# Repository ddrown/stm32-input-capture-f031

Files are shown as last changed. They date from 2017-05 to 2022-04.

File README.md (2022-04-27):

This was originally designed to accept a very low frequency pwm output (1-50Hz) and measure the SBC's frequency vs the TCXO's. That frequency data can then be fed into chrony's temperature compensation system to result in more stable time for NTP service.

Hardware is a custom designed SBC hat with microcontroller and TCXO

The TCXO's frequency vs temperature curve is measured and stored in flash in order to increase long term frequency accuracy.

The hat also contains an RTC with sub-second precision. Usually i2c RTCs will only tell you time to the nearest second, so you have to poll them to find out when the second changes. The RTC runs off the 32khz crystal, but can be measured in hardware against the TCXO with `clients/rtc compare`

Timers used
* TIM2 - main 32 bit timer, all 4 channels are setup as input capture
* TIM14 - 16 bit timer, measures RTC vs TCXO on channel 1

settings in raspi-config:

i2c enabled
(optional for gps) serial login shell disabled, serial interface enabled

/boot/config.txt:
dtparam=i2c\_arm=on
dtparam=i2c\_arm\_baudrate=400000
\# optional for gps
dtoverlay=pps-gpio,gpiopin=13

stm32 source code:

* Src/system_stm32f0xx.c - bootup, start clocks
* Src/main.c - init peripherals, main loop
* Src/stm32f0xx_hal_msp.c - init irq, init gpio routing, init clocks, etc
* Src/stm32f0xx_it.c - irq handlers (mostly call into HAL)
* Src/adc.c - measure temperature, vcc, and rtc battery
* Src/flash.c - store TCXO parameters in flash
* Src/i2c_slave.c - i2c interface to talk to SBC
* Src/timer.c - manages TIM2, TIM14, and RTC
* Src/uart.c - debug uart interface
* Drivers/STM32F0xx_HAL_Driver - stm32 Hardware Abstraction Layer (HAL)

SBC tool code:

* clients/timestamps-i2c.c - compare SBC system time vs TCXO, request via i2c
* clients/input-capture-i2c.c - compare SBC system frequency vs TCXO, via SBC output pwm
* clients/pi-pwm-setup.c - wiringPi setup SBC output pwm
* clients/pi-pwm-disable.c - wiringPi disable SBC output pwm
* clients/odroid-c2-setup - sysfs setup SBC output pwm
* clients/rtc.c - read/set/sync/manage rtc
* clients/set-calibration-data.c - get/set TCXO calibration data in flash
* clients/ds3231.c - DS3231 RTC i2c client
* clients/pcf2129.c - PCF2129 RTC i2c client
* clients/calibration.c - measure RTC vs TCXO
* clients/dump-adc.c - test comparing floating vs fixed point math

SBC library code:

* clients/adc_calc.c - read ADC data over i2c
* clients/aging.c - estimate TCXO frequency from aging effects
* clients/avg.c - calculate averages
* clients/float.c - convert between native float and i2c compatible
* clients/i2c.c - i2c interface functions
* clients/i2c_registers.c - read stm32's exported data via i2c
* clients/rtc_data.c - convert between RTC data and system time
* clients/tempcomp.c - calculate TCXO's temperature compensation
* clients/timespec.c - struct timespec utilities
* clients/vref_calc.c - adc voltage calculations

Programming the stm32 can be done via openocd on the connected SBC.

SWD programming interface is connected to SBC pins:
* 18 - dio
* 22 - clk
* 11 - rst

Example openocd configuration:
* openocd.cfg - raspberry pi & stlink example
* openocd-odroid.cfg - gpio sysfs on odroid-c2 SBC

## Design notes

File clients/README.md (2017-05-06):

# Clients to talk to the stm32 hardware

Tested clients: Raspberry Pi, Odroid C2

 * pi-pwm-setup.c - setup PWM output for the Raspberry Pi (50Hz on GPIO18 / Pin #12)
 * odroid-c2-setup - setup PWM output for the Odroid C2 (50Hz on GPIOX\_6 / Pin #33)
 * input-capture-i2c.c - poll the stm32 every second and write the average frequency over the past 128s to /run/tcxo
 * timespec.c - nanosecond timestamps handling
 * i2c.c - i2c bus code
 * ds3231.c - setup RTC DS3231 (optional)
 * rtc.c - manage rtc
 * calibration.c - dump i2c registers 1/s
 * set-calibration-data.c - set/get i2c registers
 * pihatrtc.service - put this in /etc/systemd/system/ and enable it with "systemctl enable pihatrtc"

Example chrony.conf line: `tempcomp /run/tcxo 1 0 0 1 0`

Currently setup to expect 50Hz on channel 1, 1Hz on channels 2-4.  set-calibration-data can change this

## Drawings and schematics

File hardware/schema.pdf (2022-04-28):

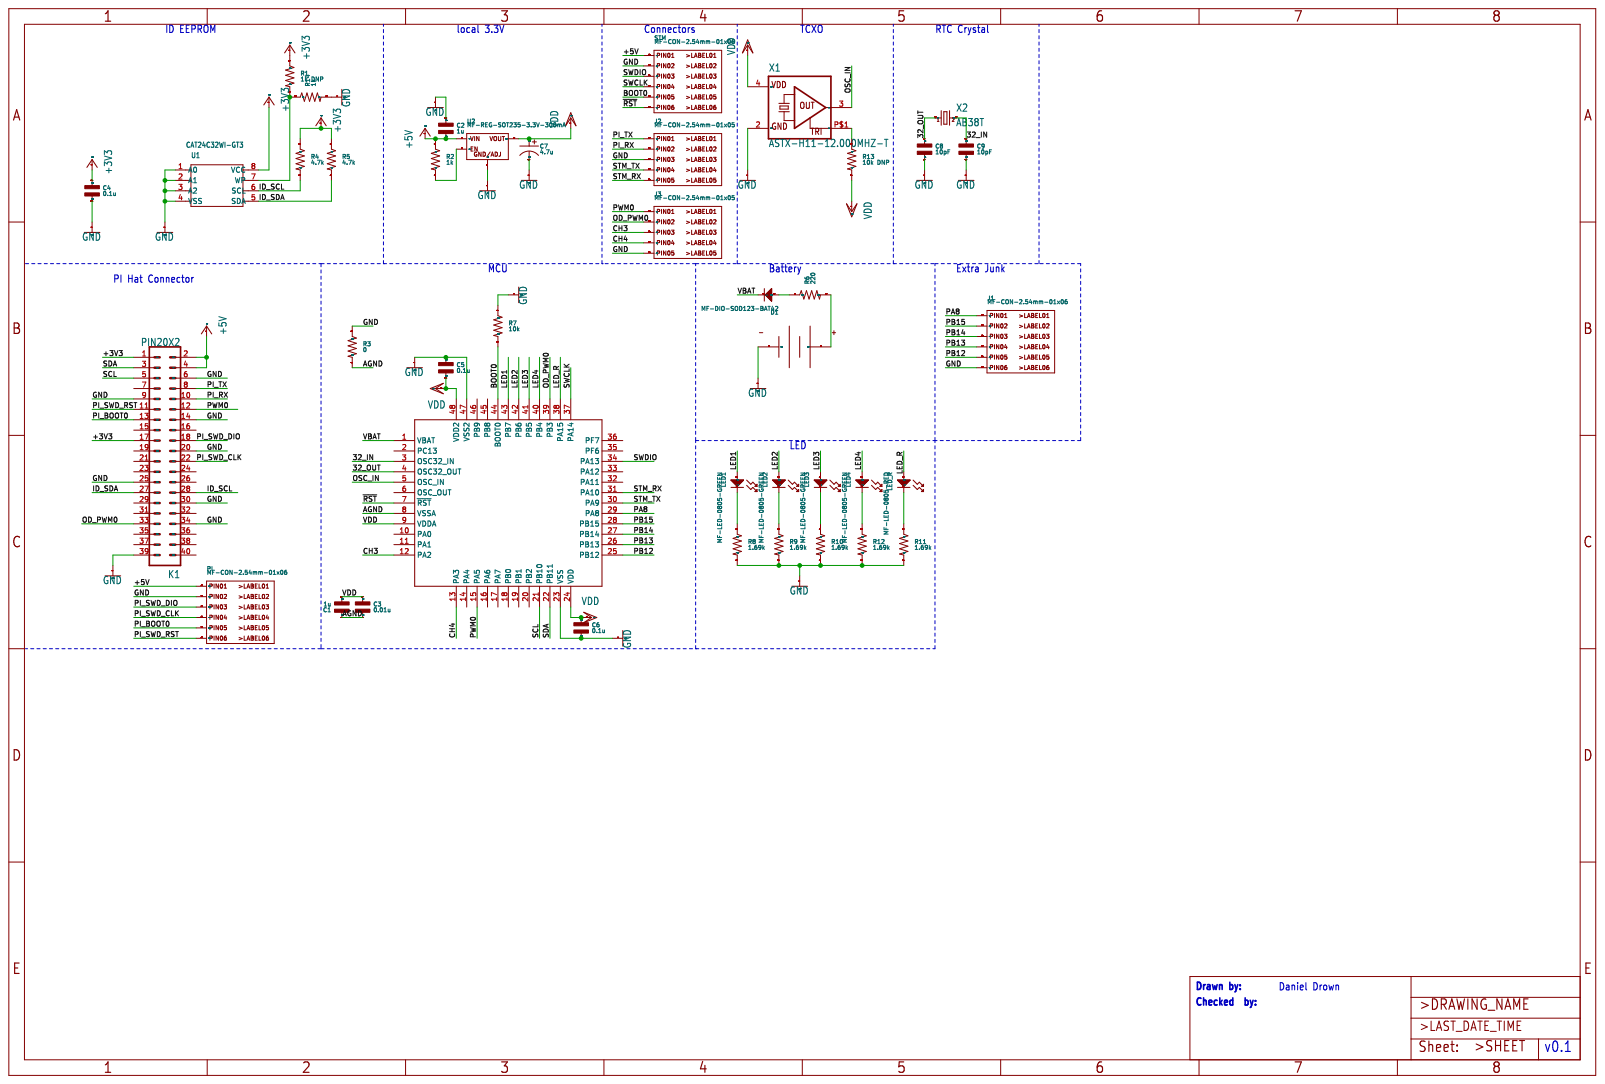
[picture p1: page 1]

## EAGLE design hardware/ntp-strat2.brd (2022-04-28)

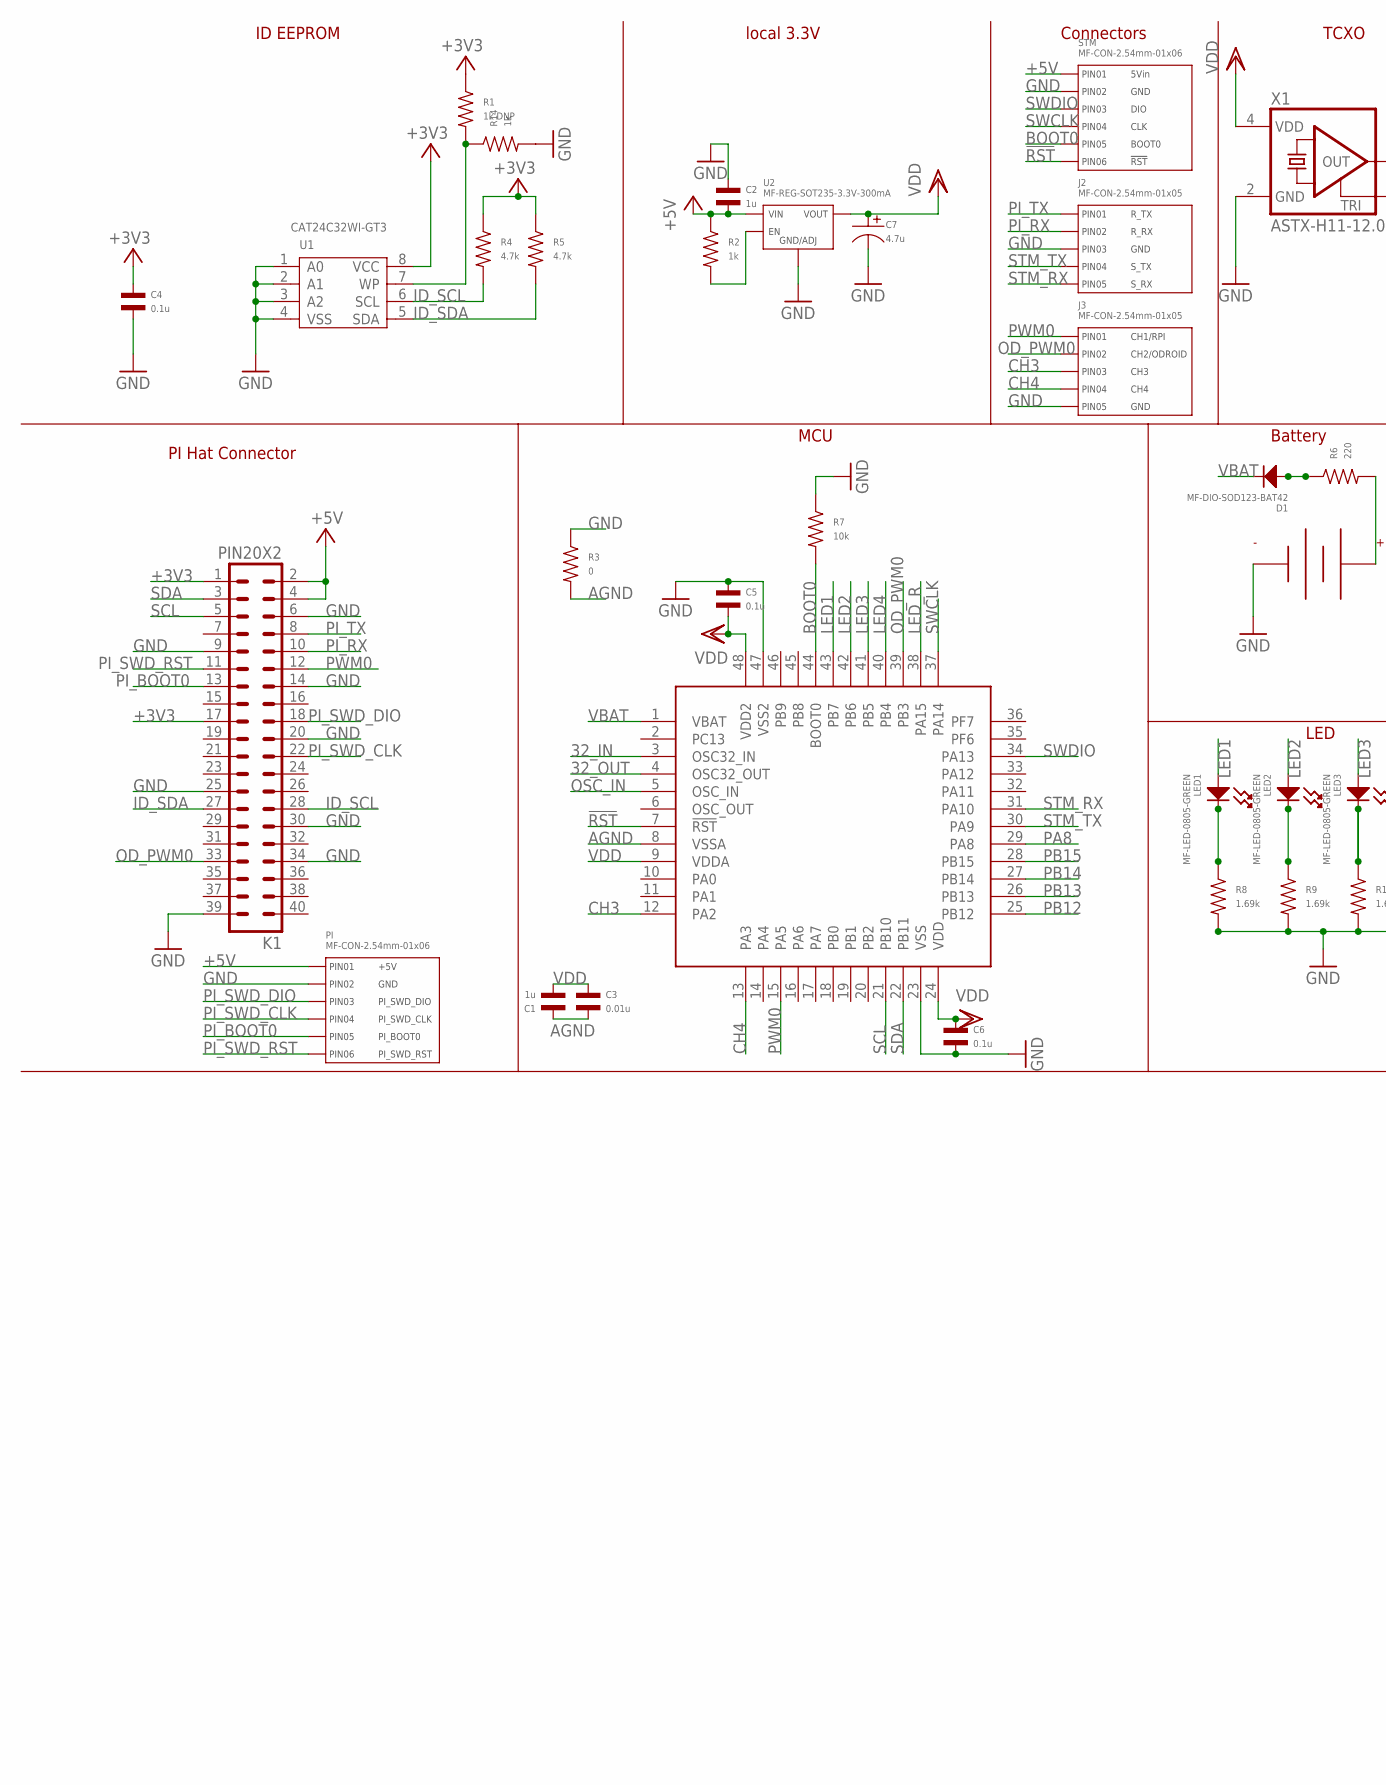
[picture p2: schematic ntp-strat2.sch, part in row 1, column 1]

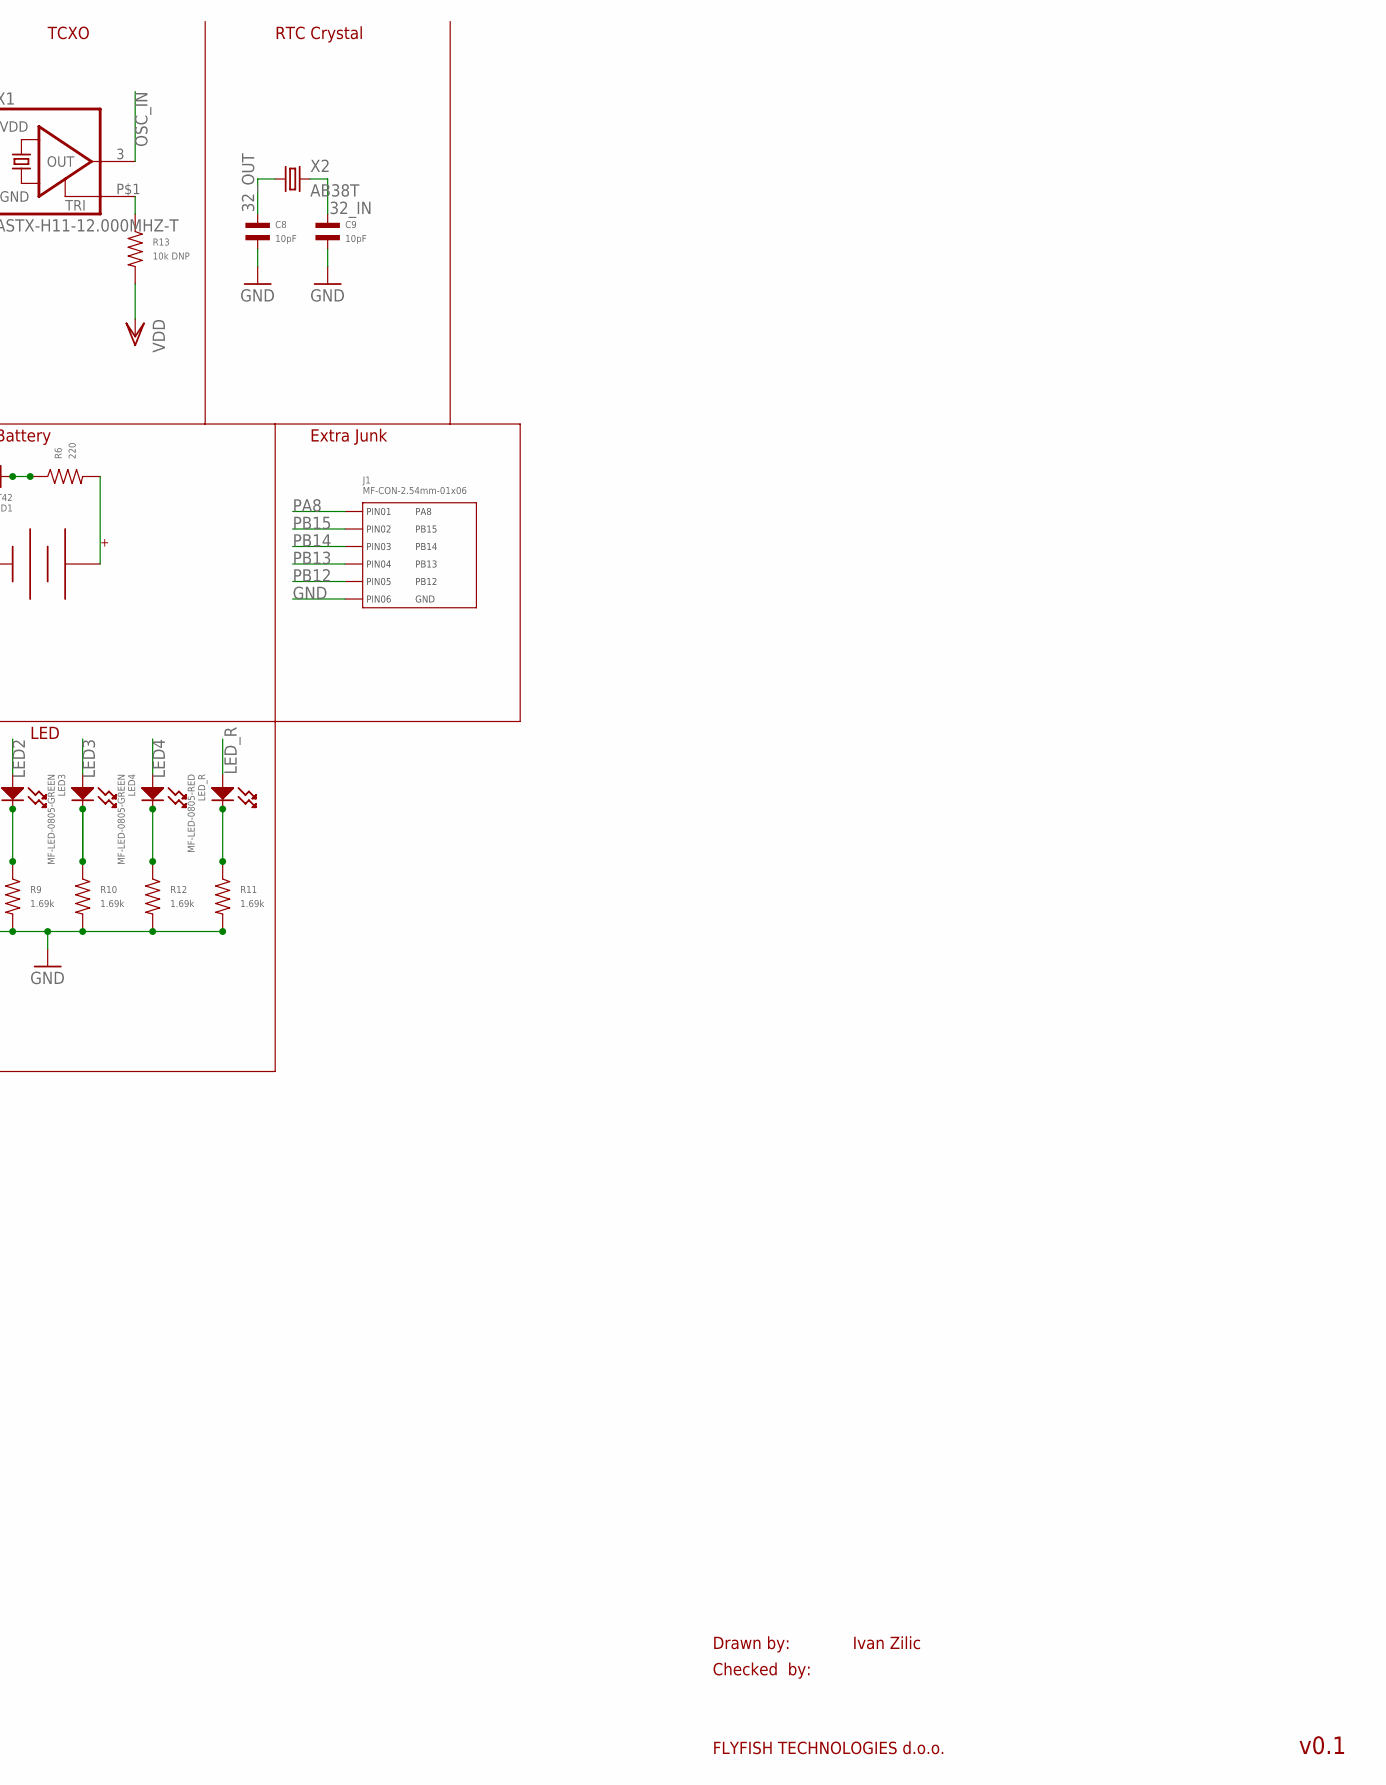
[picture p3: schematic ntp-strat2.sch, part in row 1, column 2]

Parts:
C1, C2: 1u; C0603
C3: 0.01u; C0603
C4, C5, C6: 0.1u; C0603
C7: 4.7u; CP4MM
C8, C9: 10pF; C0603
D1: MF-DIO-SOD123-BAT42; SOD-123
J1: MF-CON-2.54mm-01x06; PTH_2.54MM_01X06
J2, J3: MF-CON-2.54mm-01x05; PTH_2.54MM_01X05
K1: PIN20X2; PIN_20X2
LED1, LED2, LED3, LED4: MF-LED-0805-GREEN; LED0805
LED_R: MF-LED-0805-RED; LED0805
PI: MF-CON-2.54mm-01x06; PTH_2.54MM_01X06
R1: 1k DNP; R0603
R2, R14: 1k; R0603
R3: 0; R0603
R4, R5: 4.7k; R0603
R6: 220; R0603
R7: 10k; R0603
R8, R9, R10, R11, R12: 1.69k; R0603
R13: 10k DNP; R0603
STM: MF-CON-2.54mm-01x06; PTH_2.54MM_01X06
U1: CAT24C32WI-GT3; SOIC8-1.27-5X4MM
U2: MF-REG-SOT235-3.3V-300mA; SOT-23-5
U3: STM32F031C6T6; LQFP48-7X7
U4: BU2032SM-BT-GTR; BU2032SM
X1: ASTX-H11-12.000MHZ-T; ASVTX
X2: AB38T

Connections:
32_IN: C9.P$1, U3.3 (OSC32_IN), X2.P2 (2)
32_OUT: C8.P$1, U3.4 (OSC32_OUT), X2.P1 (1)
!RST: STM.P$6 (PIN6), U3.7 (!RST)
+3V3: C4.P$1, K1.1, K1.17, R1.P$1, R4.P$1, R5.P$1, U1.8 (VCC)
+5V: C2.P$2, K1.2, K1.4, PI.P$1 (PIN1), R2.P$1, STM.P$1 (PIN1), U2.P$1 (VIN)
AGND: C1.P$1, C3.P$2, R3.P$2, U3.8 (VSSA)
BOOT0: R7.P$2, STM.P$5 (PIN5), U3.44 (BOOT0)
CH3: J3.P$3 (PIN3), U3.12 (PA2)
CH4: J3.P$4 (PIN4), U3.13 (PA3)
GND: C2.P$1, C4.P$2, C5.P$1, C6.P$2, C7.P$2, C8.P$2, C9.P$2, J1.P$6 (PIN6), J2.P$3 (PIN3), J3.P$5 (PIN5), K1.6, K1.9, K1.14, K1.20, K1.25, K1.30, K1.34, K1.39, PI.P$2 (PIN2), R3.P$1, R7.P$1, R8.P$2, R9.P$2, R10.P$2, R11.P$2, R12.P$2, R14.P$2, STM.P$2 (PIN2), U1.1 (A0), U1.2 (A1), U1.3 (A2), U1.4 (VSS), U2.P$2 (GND/ADJ), U3.23 (VSS), U3.47 (VSS2), U4.MINUS, X1.2 (GND)
ID_SCL: K1.28, R4.P$2, U1.6 (SCL)
ID_SDA: K1.27, R5.P$2, U1.5 (SDA)
LED1: LED1.ANODE, U3.43 (PB7)
LED2: LED2.ANODE, U3.42 (PB6)
LED3: LED3.ANODE, U3.41 (PB5)
LED4: LED4.ANODE, U3.40 (PB4)
LED_R: LED_R.ANODE, U3.38 (PA15)
unnamed: R2.P$2, U2.P$3 (EN)
unnamed: LED1.CATHODE, R8.P$1
unnamed: R1.P$2, R14.P$1, U1.7 (WP)
unnamed: D1.ANODE, R6.P$1
unnamed: LED2.CATHODE, R9.P$1
unnamed: LED3.CATHODE, R10.P$1
unnamed: LED_R.CATHODE, R11.P$1
unnamed: LED4.CATHODE, R12.P$1
unnamed: R6.P$2, U4.PLUS
unnamed: R13.P$1, X1.P$1 (TRI)
OD_PWM0: J3.P$2 (PIN2), K1.33, U3.39 (PB3)
OSC_IN: U3.5 (OSC_IN), X1.3 (OUT)
PA8: J1.P$1 (PIN1), U3.29 (PA8)
PB12: J1.P$5 (PIN5), U3.25 (PB12)
PB13: J1.P$4 (PIN4), U3.26 (PB13)
PB14: J1.P$3 (PIN3), U3.27 (PB14)
PB15: J1.P$2 (PIN2), U3.28 (PB15)
PI_BOOT0: K1.13, PI.P$5 (PIN5)
PI_RX: J2.P$2 (PIN2), K1.10
PI_SWD_CLK: K1.22, PI.P$4 (PIN4)
PI_SWD_DIO: K1.18, PI.P$3 (PIN3)
PI_SWD_RST: K1.11, PI.P$6 (PIN6)
PI_TX: J2.P$1 (PIN1), K1.8
PWM0: J3.P$1 (PIN1), K1.12, U3.15 (PA5)
SCL: K1.5, U3.21 (PB10)
SDA: K1.3, U3.22 (PB11)
STM_RX: J2.P$5 (PIN5), U3.31 (PA10)
STM_TX: J2.P$4 (PIN4), U3.30 (PA9)
SWCLK: STM.P$4 (PIN4), U3.37 (PA14)
SWDIO: STM.P$3 (PIN3), U3.34 (PA13)
VBAT: D1.CATHODE, U3.1 (VBAT)
VDD: C1.P$2, C3.P$1, C5.P$2, C6.P$1, C7.P$1, R13.P$2, U2.P$5 (VOUT), U3.9 (VDDA), U3.24 (VDD), U3.48 (VDD2), X1.4 (VDD)

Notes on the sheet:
Drawn by:
Checked by:
FLYFISH TECHNOLOGIES d.o.o.
Ivan Zilic
v0.1
ID EEPROM
PI Hat Connector
local 3.3V
Connectors
TCXO
RTC Crystal
Battery
MCU
LED
Extra Junk

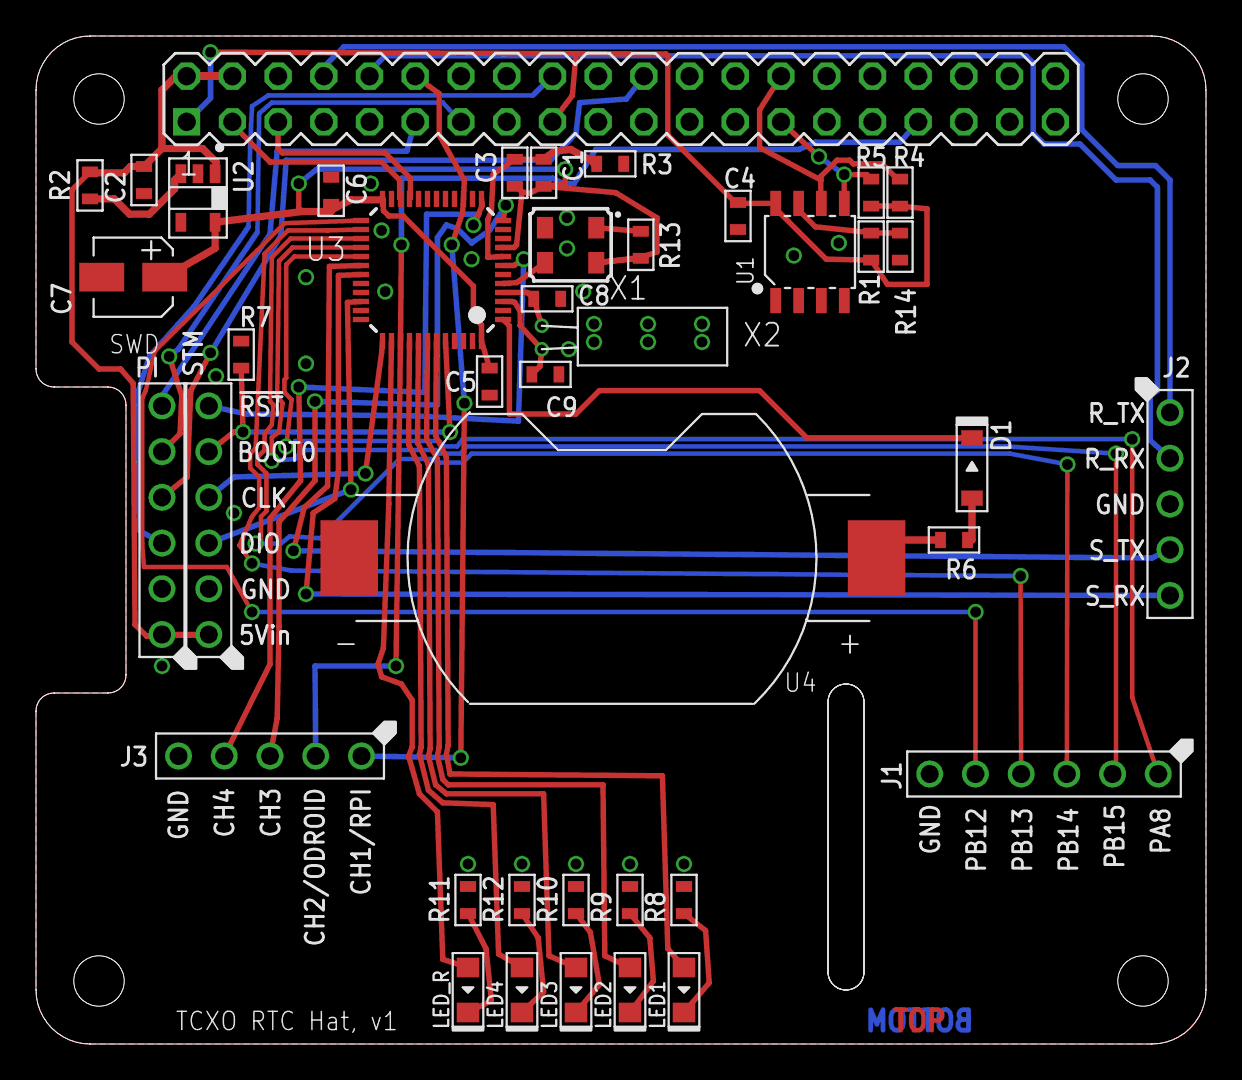
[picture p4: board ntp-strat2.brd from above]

Board: 2 copper layers, 65.0 x 56.0 mm, 41 parts (0 on the bottom side), 49 nets.

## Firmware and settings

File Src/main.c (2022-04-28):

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
/* Includes ------------------------------------------------------------------*/
#include "main.h"

/* USER CODE BEGIN Includes */
#include "uart.h"
#include "timer.h"
#include "i2c_slave.h"
#include "adc.h"
/* USER CODE END Includes */

 ADC_HandleTypeDef hadc;

I2C_HandleTypeDef hi2c1;

RTC_HandleTypeDef hrtc;

TIM_HandleTypeDef htim2;
TIM_HandleTypeDef htim14;

UART_HandleTypeDef huart1;

/* USER CODE BEGIN PV */

/* USER CODE END PV */

void SystemClock_Config(void);
static void MX_GPIO_Init(void);
static void MX_ADC_Init(void);
static void MX_I2C1_Init(void);
static void MX_RTC_Init(void);
static void MX_TIM2_Init(void);
static void MX_TIM14_Init(void);
static void MX_USART1_UART_Init(void);
/* USER CODE BEGIN PFP */

/* USER CODE END PFP */

/**
  * @brief  The application entry point.
  * @retval int
  */
int main(void)
{
  /* MCU Configuration--------------------------------------------------------*/

  /* Reset of all peripherals, Initializes the Flash interface and the Systick. */
  HAL_Init();

  /* Configure the system clock */
  SystemClock_Config();

  /* Initialize all configured peripherals */
  MX_GPIO_Init();
  MX_ADC_Init();
  MX_I2C1_Init();
  MX_RTC_Init();
  MX_TIM2_Init();
  MX_TIM14_Init();
  MX_USART1_UART_Init();
  /* USER CODE BEGIN 2 */
  HAL_ADCEx_Calibration_Start(&hadc);
  i2c_slave_start();
  timer_start();
  rtc_start();
  /* USER CODE END 2 */

  /* Infinite loop */
  /* USER CODE BEGIN WHILE */
  while (1)
  {
    /* USER CODE END WHILE */

    /* USER CODE BEGIN 3 */

    /* debugging code
    print_timer_status();
    i2c_show_data();
     */
    adc_poll();
    HAL_Delay(100);
  }
  /* USER CODE END 3 */
}

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


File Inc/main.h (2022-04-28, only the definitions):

#define LED_R_Pin GPIO_PIN_15
#define LED_R_GPIO_Port GPIOA
#define LED4_Pin GPIO_PIN_4
#define LED4_GPIO_Port GPIOB
#define LED3_Pin GPIO_PIN_5
#define LED3_GPIO_Port GPIOB
#define LED2_Pin GPIO_PIN_6
#define LED2_GPIO_Port GPIOB
#define LED1_Pin GPIO_PIN_7
#define LED1_GPIO_Port GPIOB

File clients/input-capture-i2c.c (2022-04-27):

#include <errno.h>
#include <stdlib.h>
#include <unistd.h>
#include <stdint.h>
#include <stdio.h>
#include <string.h>
#include <time.h>
#include <math.h>
#include <ctype.h>

#include "i2c.h"
#include "timespec.h"
#include "i2c_registers.h"
#include "adc_calc.h"
#include "vref_calc.h"
#include "aging.h"
#include "tempcomp.h"

#define SUMMARIZE_INTERVAL 64
struct per_second_stats {
  time_t when;
  uint32_t irq_to_i2c_ms;
  uint32_t status;
  uint32_t sleep_ms;
  double added_offset_ns[INPUT_CHANNELS];
  double tempcomp;
  float aging;
  double main_freq_32s;
  double main_freq_64s;
  float temp_f;
  float vref;
  float vbat;
} stats[SUMMARIZE_INTERVAL];
uint8_t stats_i = 0;

// current code assumptions: main channel never stops
struct icap_config {
  uint8_t verbose;
  uint8_t main_channel;
  uint8_t main_channel_hz;
} config;

#define AVERAGING_CYCLES 65
#define PPM_INVALID -1000000.0
#define AIM_AFTER_MS 5
#define TCXO_TEMPCOMP_TEMPFILE "/run/.tcxo"
#define TCXO_TEMPCOMP_FILE "/run/tcxo"
#define TCXO_FREQ_TEMPFILE "/run/.tcxo-freq"
#define TCXO_FREQ_FILE "/run/tcxo-freq"

// status_flags bitfields
#define STATUS_BAD_CH1        0b1
#define STATUS_BAD_CH2       0b10
#define STATUS_BAD_CH3      0b100
#define STATUS_BAD_CH4     0b1000
// BAD_CHANNEL_STATUS takes 0-indexed channels
#define BAD_CHANNEL_STATUS(x) (1 << (x))

static uint16_t wrap_add(int16_t a, int16_t b, uint16_t modulus) {
  a = a + b;
  if(a < 0) {
    a += modulus;
  }
  return a;
}

static uint16_t wrap_sub(int16_t a, int16_t b, uint16_t modulus) {
  return wrap_add(a, -1 * b, modulus);
}

static void print_ppm(float ppm) {
  if(ppm < 500 && ppm > -500) {
    printf("%1.3f ", ppm);
  } else {
    printf("- ");
  }
}

static void write_freqfile(float ppm, const char *tempfile, const char *finalfile) {
  FILE *tcxo;

  if(ppm > 500 || ppm < -500) {
    return;
  }

  tcxo = fopen(tempfile,"w");
  if(tcxo == NULL) {
    perror("fopen");
    printf("was trying to open file %s\n", tempfile);
    exit(1);
  }
  fprintf(tcxo, "%1.3f\n", ppm);
  fclose(tcxo);
  rename(tempfile, finalfile);
}

static void write_tcxo_ppm(float ppm) {
  write_freqfile(ppm, TCXO_FREQ_TEMPFILE, TCXO_FREQ_FILE);
}

static void write_tempcomp_ppm(float ppm) {
  write_freqfile(ppm, TCXO_TEMPCOMP_TEMPFILE, TCXO_TEMPCOMP_FILE);
}

// modifies cycles, first_cycle, last_cycle
static void store_added_offset(double added_offset_ns, struct timespec *cycles, uint16_t *first_cycle, uint16_t *last_cycle) {
  struct timespec *previous_cycle = NULL;
  uint16_t this_cycle_i;

  this_cycle_i = (*last_cycle + 1) % AVERAGING_CYCLES;
  if(*first_cycle != *last_cycle) {
    previous_cycle = &cycles[*last_cycle];
    if(*first_cycle == this_cycle_i) { // we've wrapped around, move the first pointer forward
      *first_cycle = (*first_cycle + 1) % AVERAGING_CYCLES;
    }
  }

  cycles[this_cycle_i].tv_sec = 0;
  cycles[this_cycle_i].tv_nsec = added_offset_ns;
  if(previous_cycle != NULL) {
    add_timespecs(&cycles[this_cycle_i], previous_cycle);
  }

  *last_cycle = this_cycle_i;
}

static float calc_ppm_2(struct timespec *end, struct timespec *start, uint16_t seconds) {
  double diff_s;
  struct timespec diff;
  diff.tv_sec = end->tv_sec;
  diff.tv_nsec = end->tv_nsec;

  sub_timespecs(&diff, start);
  diff_s = diff.tv_sec + diff.tv_nsec / 1000000000.0;

  float ppm = diff_s * 1000000.0 / seconds;
  return ppm;
}

static float calc_ppm(int16_t number_points, uint16_t last_cycle_index, uint16_t seconds, struct timespec *cycles) {
  float ppm = PPM_INVALID; // default: invalid PPM

  if(number_points >= seconds) {
    uint16_t start_index = wrap_sub(last_cycle_index, seconds, AVERAGING_CYCLES);
    ppm = calc_ppm_2(&cycles[last_cycle_index], &cycles[start_index], seconds);
  }

  return ppm;
}

static uint32_t calculate_sleep_ms(uint32_t milliseconds_now, uint32_t milliseconds_irq) {
  uint32_t sleep_ms = 1000 + AIM_AFTER_MS - (milliseconds_now - milliseconds_irq);
  if(sleep_ms > 1000+AIM_AFTER_MS) {
    sleep_ms = 1000+AIM_AFTER_MS;
  } else if(sleep_ms < 1) {
    sleep_ms = 1;
  }
  return sleep_ms;
}

// modifies added_offset_ns, status_flags
static int add_cycles(uint32_t *status_flags, double *added_offset_ns, const struct i2c_registers_type *i2c_registers) {
  static uint32_t previous_cycles[INPUT_CHANNELS] = {0,0,0,0};
  static uint8_t previous_count[INPUT_CHANNELS] = {0,0,0,0};
  static uint32_t primary_ms_last = 0;
  int retval = 1;

  for(uint8_t i = 0; i < INPUT_CHANNELS; i++) {
    int32_t diff;
    
    if(i == config.main_channel-1) {
      uint32_t milliseconds = i2c_registers->milliseconds_irq_primary - primary_ms_last;
      if(milliseconds < 2000 && milliseconds > 900) {
        diff = i2c_registers->tim2_at_cap[i] - previous_cycles[i] - EXPECTED_FREQ;
        added_offset_ns[i] = diff * 1000000000.0 / EXPECTED_FREQ;
      } else {
        added_offset_ns[i] = 0;
        retval = 0;
	*status_flags |= BAD_CHANNEL_STATUS(i);
      }
      primary_ms_last = i2c_registers->milliseconds_irq_primary;
    } else {
      uint8_t diff_count = i2c_registers->ch_count[i] - previous_count[i];

      if(diff_count == 1 || diff_count == 2) { // treating count as # of seconds, assume 1s/2s=ok, other values=invalid
	diff = i2c_registers->tim2_at_cap[i] - previous_cycles[i] - (EXPECTED_FREQ * diff_count);
	added_offset_ns[i] = diff * 1000000000.0 / (EXPECTED_FREQ * diff_count);
      } else {
	added_offset_ns[i] = 0;
	*status_flags |= BAD_CHANNEL_STATUS(i);
      }
    }

    previous_cycles[i] = i2c_registers->tim2_at_cap[i];
    previous_count[i] = i2c_registers->ch_count[i];
  }

  return retval;
}

static void before_loop() {
  if(config.verbose) {
    printf("ts delay status sleepms 1ppm 2ppm 3ppm 4ppm tempcomp 32s_ppm 64s_ppm ");
    printf("int-temp vref vbat aging");
    printf("\n");
  }
}

static void log_loop(struct per_second_stats *cur_stats) {
  if(config.verbose) {
    printf("%lu %2u %3o %4u ",
       cur_stats->when,
       cur_stats->irq_to_i2c_ms,
       cur_stats->status,
       cur_stats->sleep_ms
       );
    for(uint8_t i = 0; i < INPUT_CHANNELS; i++) {
      printf("%.3f ", cur_stats->added_offset_ns[i]/1000.0);
    }

    printf(" %3.1f ",cur_stats->tempcomp);

    print_ppm(cur_stats->main_freq_32s);
    print_ppm(cur_stats->main_freq_64s);

    printf("%.4f ", cur_stats->temp_f);
    printf("%.5f ", cur_stats->vref);
    printf("%.5f ", cur_stats->vbat);

    printf("%.3f ", cur_stats->aging);

    printf("\n");
    fflush(stdout);
  }
}

static void print_data_u32(uint32_t *data, uint32_t count) {
  uint32_t min, max, sum;
  if(count == 0) {
    printf("- ");
    return;
  }
  min = data[0];
  max = data[0];
  sum = 0;
  for(uint32_t i = 0; i < count; i++) {
    if(min > data[i])
      min = data[i];
    if(max < data[i])
      max = data[i];
    sum += data[i];
  }
  printf("%u/%.1f/%u ", min, sum/(float)count, max);
}
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

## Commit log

2017-03-19 add LED GPIOs
2017-04-29 ADC and RTC support
2017-04-29 cubemx version update and pin redefinitions
2017-04-30 calibration scripts
2017-05-01 move rtc year before set_rtc, allow rtc values to be set via i2c, copy i2c page with interrupts off on set page operation
2017-05-01 set rtc time, set rtc calibration, set rtc subsecond adjust
2017-05-09 GMT timezone is no longer needed
    [calibration.c, rtc.c]
2017-05-09 input-capture-i2c for the f031
2017-05-27 added verbose mode, default is print every 64s
2017-06-13 compare LSE to TCXO and set RTC calibration values
2017-09-23 add aging to input-capture-i2c
2017-09-23 add aging to input-capture-i2c #2
2017-10-11 page4/page 5 registers
    page4: new item: tim2 count on top of second
    page5: new items:
    current tim2 count
    current millis count
    5x 32 bit RTC general purpose registers
2017-10-16 hse offset, nanosecond timers
2018-01-25 testing fixed point math
    [dump-adc.c]
2022-04-27 make i2c bus configurable
2022-04-27 query via i2c, print offset & adjust for tempcomp
2022-04-27 remove pi-pwm-setup from default build, add dump-adc+timestamps-i2c
2022-04-28 hardware design files
    [ntp-strat2.brd, ntp-strat2.sch]
2022-04-28 upgrade STM32Cube Firmware to V1.11.3
2022-04-28 Error_Handler changed with newer firmware
    [timer.c]
2022-05-05 flash and reboot from stm32mp157

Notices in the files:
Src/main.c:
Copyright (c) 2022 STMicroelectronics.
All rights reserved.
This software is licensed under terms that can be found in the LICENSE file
